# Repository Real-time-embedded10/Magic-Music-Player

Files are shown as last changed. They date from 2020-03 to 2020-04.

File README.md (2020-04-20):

Magic-Music-Player
==
This project aims to design a real-time gesture-based Magic Music System, capable of adding sound effects (including tone and/or volume) in real time using defined hand gestures.<br>

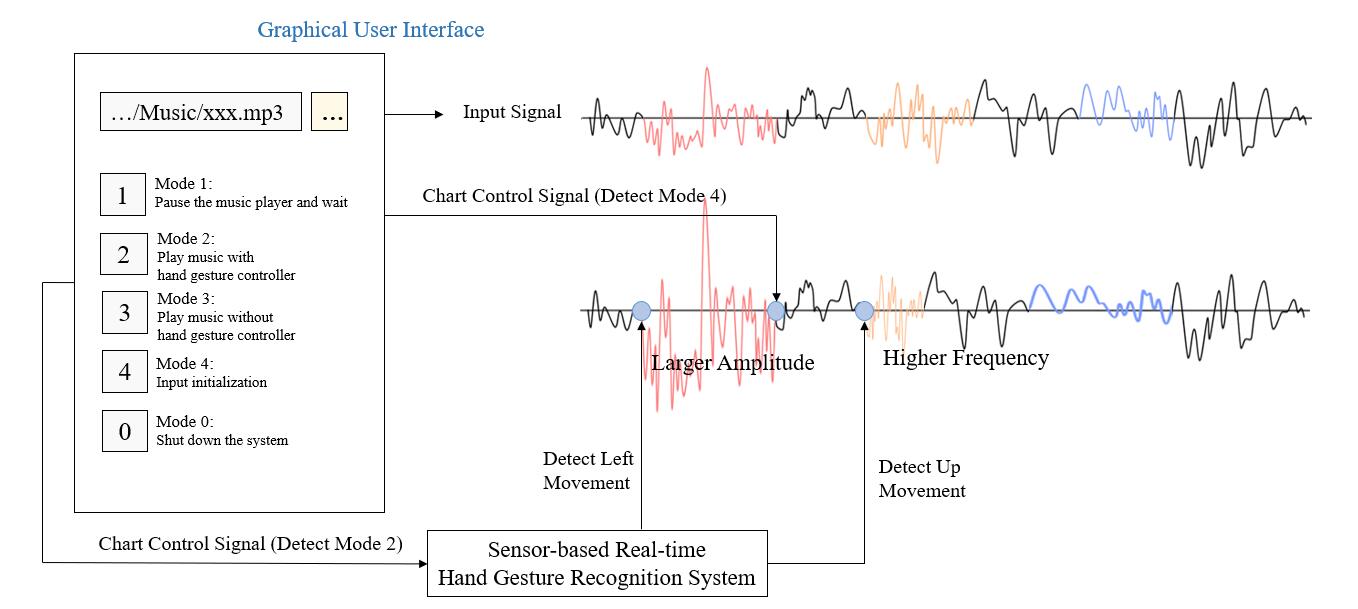
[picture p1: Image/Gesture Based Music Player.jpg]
 

Introduction
--
**Main Function**<br>
Export source from PC; <br>
Equipped control UI on PC; <br>
Recognize Hand Gesture in real time; <br>
Change music tone/volume by gestures in the process of playing music.<br>

**Hardware Requirement**<br>
Accelerometer and Gyroscope: Sensors of Hand Gesture <br>
Raspberry Pi: Real-time Hand Gesture Recognition <br>
PC: Graphical User Interface and UI Music Player <br>

**Software Requirement**<br>
I2C system to obtain data from sensors. <br>
Pre-processing method to extract useful information of hand gestures. <br>
Marchine learning model to classify hand gestures.<br>
Communication system to realize wireless connection bewteen PC and raspberry pi.<br>
Digital signal processing algorithm to process song based on control signal received from raspberry pi.<br>

Further information is available at our [wiki](https://github.com/Real-time-embedded10/Magic-Music-Player/wiki).<br>

Our Work
--
A current circuit was designed, and it can obtain information about accelerometer output, gyroscope output and temperature stably. The basic component used was MPU6050.<br>
Here is the PCB Layout and Connection. <br>
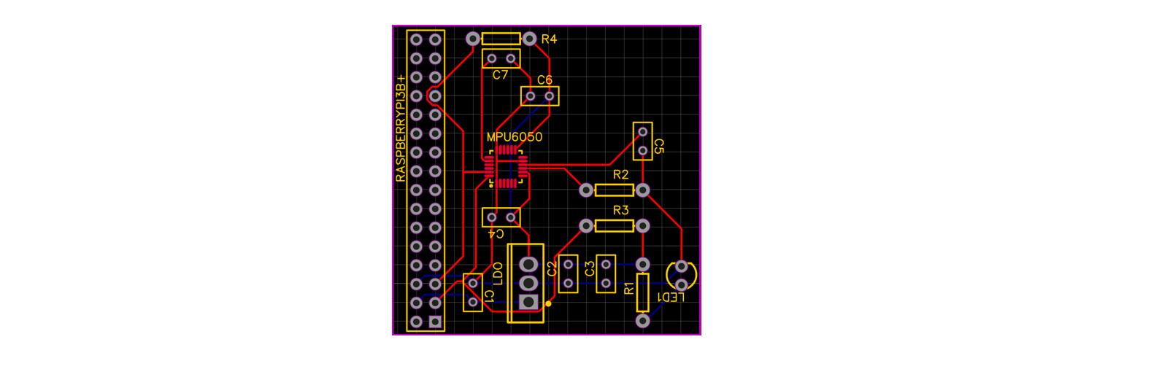
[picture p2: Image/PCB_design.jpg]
<br>

A real-time sensor-based dynamic hand gesture recognition system in raspberry pi, capable of automatically identifying whether a gesture is inputted and then translating it in the form of text, is introduced. The recognition result will be used as control signal sent to pc to control signal processing. <br>
[Here is C++ codes](https://github.com/Real-time-embedded10/Magic-Music-Player/tree/master/Software/Hand%20Gesture%20Recognition/Real%20Time%20Recognition%20System) that use Raspberry pi to recognize hand gesture in real time. <br>
Besides, a [DATABASE](https://github.com/Real-time-embedded10/Magic-Music-Player/tree/master/Software/Hand%20Gesture%20Recognition/DATABASE), including 6 hand gestures, is established. <br>
Codes used to [machine learning model training](https://github.com/Real-time-embedded10/Magic-Music-Player/tree/master/Software/Hand%20Gesture%20Recognition/Software%20Used%20in%20Database%20Establishment) and [model testing](https://github.com/Real-time-embedded10/Magic-Music-Player/tree/master/Software/Hand%20Gesture%20Recognition/Software%20Used%20in%20Testing) are also avaiable in this Repository.<br>
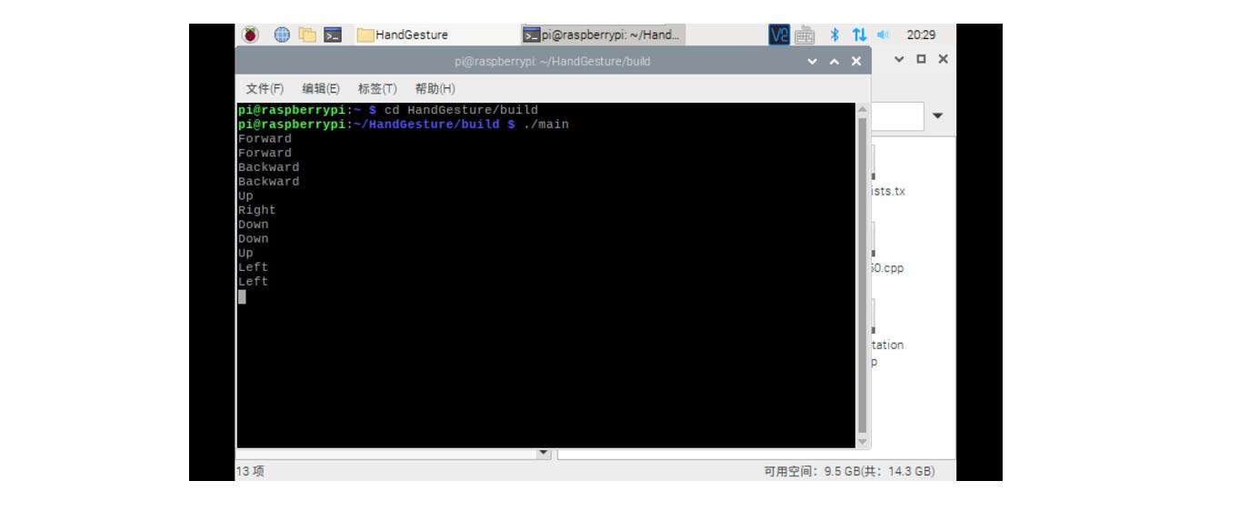
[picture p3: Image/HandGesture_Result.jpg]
<br>
<br>

This project's UI design contains two parts: [UI on the PC](https://github.com/Real-time-embedded10/Magic-Music-Player/tree/master/Software/Digital%20Signal%20Processing%20and%20UI%20Design/PC) and [UI on the raspberry Pi](https://github.com/Real-time-embedded10/Magic-Music-Player/tree/master/Software/Digital%20Signal%20Processing%20and%20UI%20Design/Raspberry%20pi).<br>
UI on the PC can work as a music player while receiving control signal generated by hand gesture to realize designed functions by calling defined libraries.<br>
UI on the raspberry pi is responsible for connecting to pc and sending signal to PC. owing to the coronavirus, UI on raspberry also helps to test the communication between PC and raspberry pi.<br>
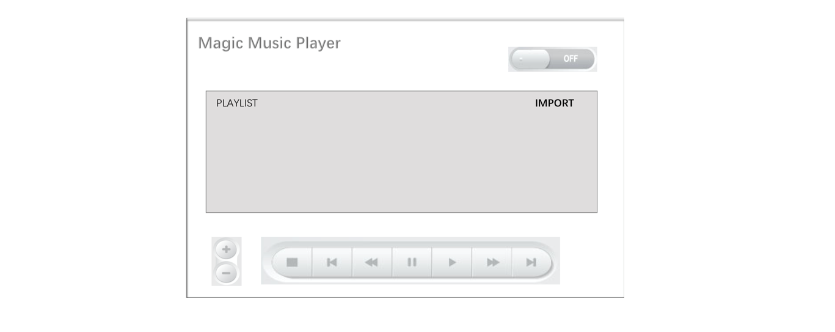
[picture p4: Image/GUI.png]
<br>

Pre-Requirement
--
Install libraries in Raspberry pi.
```
sudo apt-get install i2c-tools
sudo apt-get install wiringpi
sudo apt-get install qt5-default
sudo apt-get install qtcreator
```
and make sure that all relevant files are in one folder.<br>

To Run
--
```
cmake .
make
./main
```

Authors
--
**tashanguanyan** - Xinyun Jiang (2227272J): I2C system, Hand Gesture Recognition (Database Establishment, Machine Learning Model Training and Real-time Recoginition System).<br>
**YangDING0201** - Yang Ding (2492952D): UI MusicPlayer for PC & Rasberry Pi (Communication and Digital Signal Processing).<br>
**LianfengWu** - Lianfeng Wu (2227370W): Hardware (PCB Design). <br>
<br>
Please follow us [Twitter](https://twitter.com/MusicTeam10).<br>

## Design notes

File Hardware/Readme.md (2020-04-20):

Introduction
==
The core component in the hardware design is the MPU6050 chip, which can stably obtain the accelerometer output, gyroscope output, and temperature. The MPU6050 in the project is used to determine the direction of the hand gestures. At the same time, an LDO circuit is used in our circuit design to provide a stable 3.3V power supply for the MPU6050 to avoid burning the core chip with too high a voltage. The main component of the LDO circuit is LM7803, which can stably output 5V input voltage as 3.3V output voltage.<br>

For more information about component and circuit design, please refer to our [wiki](https://github.com/Real-time-embedded10/Magic-Music-Player/wiki/Hardware-Design).

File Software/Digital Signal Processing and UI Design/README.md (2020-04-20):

UI Design for Magic Music Player
==
The GUI design uses QT development enviroment. 

Introduction
--
**PC**<br>
This folder contains code for building GUI software on Windows and a packaged software program.[click here](https://github.com/Real-time-embedded10/Magic-Music-Player/edit/master/Software/Digital%20Signal%20Processing%20and%20UI%20Design/PC)
 <br>

* *Main Function* <br>
Import music files from PC database and build playlist; <br>
reallize basic functions of music player(Play, stop, Next track, Previous track, change playrate etc.); <br>
build communication with raspberry pi via tcp socket. <br>

**Raspberry Pi**<br>
This folder contains code for building GUI software on raspberry pi.[click here](https://github.com/Real-time-embedded10/Magic-Music-Player/tree/master/Software/Digital%20Signal%20Processing%20and%20UI%20Design/Raspberry%20pi) <br>

* *Main Function* <br>
Realize graphical connection with PC; <br>
help to test signal transmission with PC; <br>
read the signal from gesture recognition and transmit to PC. <br>
Notice: <br>
Gesture recognition files should be included in this folder to provide control signals.

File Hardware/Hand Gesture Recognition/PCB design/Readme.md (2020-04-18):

MPU6050
==
MPU-60X0 is the world's first 9-axis motion processor. It integrates a 3-axis MEMS gyroscope to measure angle, a 3-axis MEMS accelerometer to measure acceleration, and a scalable digital motion processor (DMP), which can be connected to a third-party digital sensor using I2C interface , such as a magnetometer. After expansion, it can output a 9-axis signal through its I2C interface. MPU-60X0 can also connect non-inertial digital sensors, such as pressure sensors, through its I2C interface. DMP receives and processes data from gyroscopes, accelerometers, and external sensors. The processing results can be read from DMP registers, or buffered by FIFO, and output posture-resolved data to the application side through the main I2C interface.<br>

The MPU-60X0 uses three 16-bit ADCs for the gyroscope and accelerometer, respectively, and converts the analog value it measures into a digital output. In order to accurately track fast and slow movements, the measurement range of the sensor is user-controllable, the gyro measurement range is ± 250, ± 500, ± 1000, ± 2000 ° / sec (dps), and the accelerometer measurement range is ± 2, ± 4, ± 8, ± 16g (gravity acceleration). A 1024-byte FIFO helps reduce system power consumption. Communication with all device registers uses 400kHz I2C interface or 1MHz SPI interface (SPI is only available for MPU-6000). For applications that require high-speed transmission, 20MHz SPI is available for reading and interrupting registers. In addition, a temperature sensor and an oscillator with only ± 1% variation in the working environment are embedded on the chip. The chip size is 4 × 4 × 0.9mm, and it adopts QFN package (leadless square package), which can withstand a maximum of 10000g shock, and has a programmable low-pass filter. Regarding power supply, MPU-60X0 can support VDD range 2.5V ± 5%, 3.0V ± 5%, or 3.3V ± 5%. In addition, MPU-6050 also has a VLOGIC pin, which is used to provide logic levels for I2C output. The VLOGIC voltage can be 1.8 ± 5% or VDD.<br>

**Features of MPU6050 include:**<br>
①	Digitally output 6-axis or 9-axis (requires external magnetic sensor) rotation matrix, quaternion, Euler Angle forma fusion calculation data (requires DMP support).<br>
②	3-axis angular velocity sensor (gyroscope) with 131 LSBs / ° / sec sensitivity and full-scale sensing range of ± 250, ± 500, ± 1000 and ± 2000 ° / sec.<br>
③	Integrated 3-axis acceleration sensor with programmable control range of ± 2g, ± 4g, ± 8g and ± 16g.<br>
④	Remove the sensitivity between the accelerator and the gyroscope axis, reduce the influence of the setting and the drift of the sensor.<br>
⑤	Built-in DMP engine can reduce the load of complex fusion calculation data of MCU, sensor synchronization, posture sensing, etc.<br>
⑥	Built-in operation time deviation and magnetic sensor calibration calculation technology, eliminating the need for customers to perform additional calibration.<br>
⑦	Coming with a digital temperature sensor.<br>
⑧	With digital input synchronization pin (Sync pin) supports video electronic shadow stabilization technology and GPS.<br>
⑨	Programmable interruption, support gesture recognition, panning, zooming in and out of the screen, scrolling, rapid descent interruption, high-G interruption, zero motion sensing, touch sensing, shaking sensing function.<br>
⑩	VDD power supply voltage is 2.5V ± 5%, 3.0V ± 5%, 3.3V ± 5%; VLOGIC can be as low as 1.8V ± 5%.<br>
⑪	Gyroscope working current: 5mA, gyroscope standby current: 5uA; accelerator working current: 500uA, accelerator power saving mode current: 40uA @ 10Hz.<br>
⑫	Comes with 1024-byte FIFO, which helps reduce system power consumption.<br>
⑬	I2C communication interface up to 400Khz.<br>
⑭	Ultra-small package size: 4x4x0.9mm (QFN).<br>

**Circuit Design**<br>
The Block Diagram of MPU6050:<br>
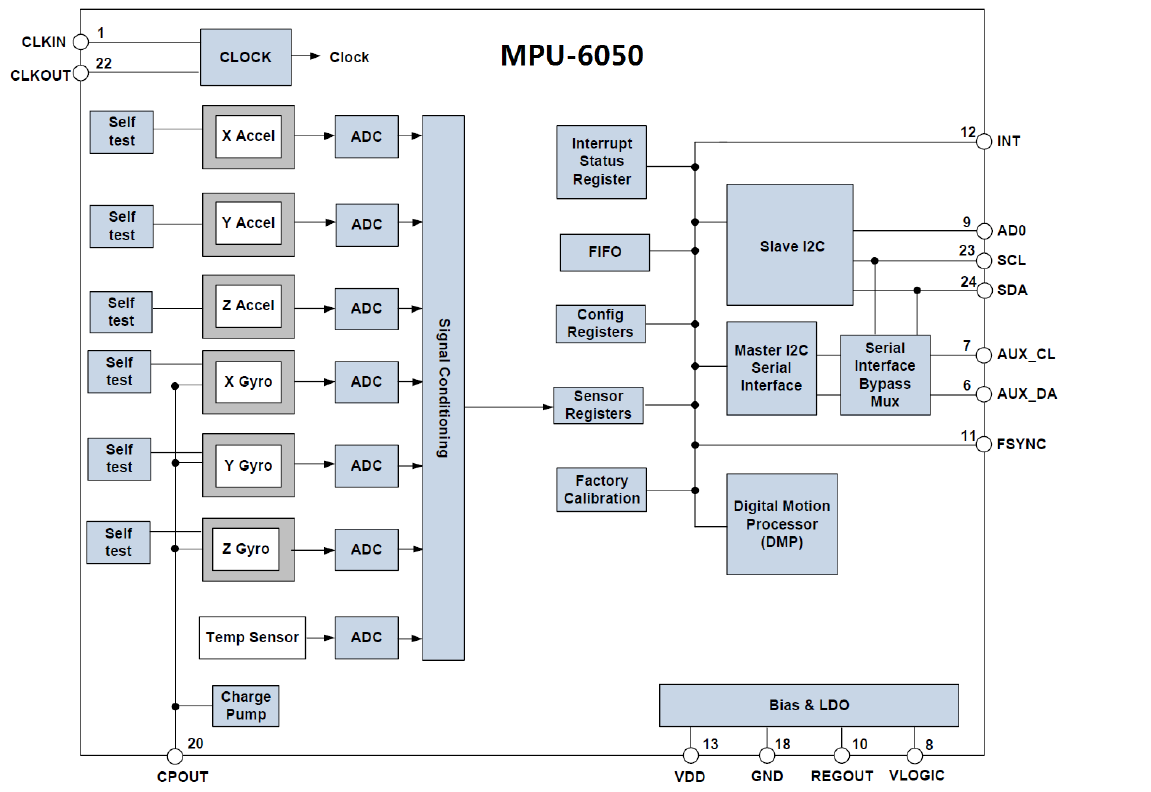
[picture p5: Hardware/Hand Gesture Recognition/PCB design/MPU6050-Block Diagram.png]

The above picture is the internal structure diagram of MPU6050. Among them, SCL and SDA are I2C interfaces connected to MCU. Raspberry Pi controls MPU6050 through this I2C interface. There is also an I2C interface: AUX_CL and AUX_DA. This interface can be used to connect external slave devices. For example, magnetic sensors, so that a nine-axis sensor can be formed. VLOGIC is the voltage of the IO port. This pin can be as low as 1.8V. We generally connect it directly to VDD. AD0 is the address control pin from the I2C interface (connected to MCU). This pin controls the lowest bit of the IIC address. If it is connected to GND, the I2C address of MPU6050 is: 0X68, if it is connected to VDD, it is 0X69. Note: The address here does not contain the lowest bit of data transmission (the lowest bit is used to indicate read and write).<br>

The Schematic Circuit Diagram:<br>
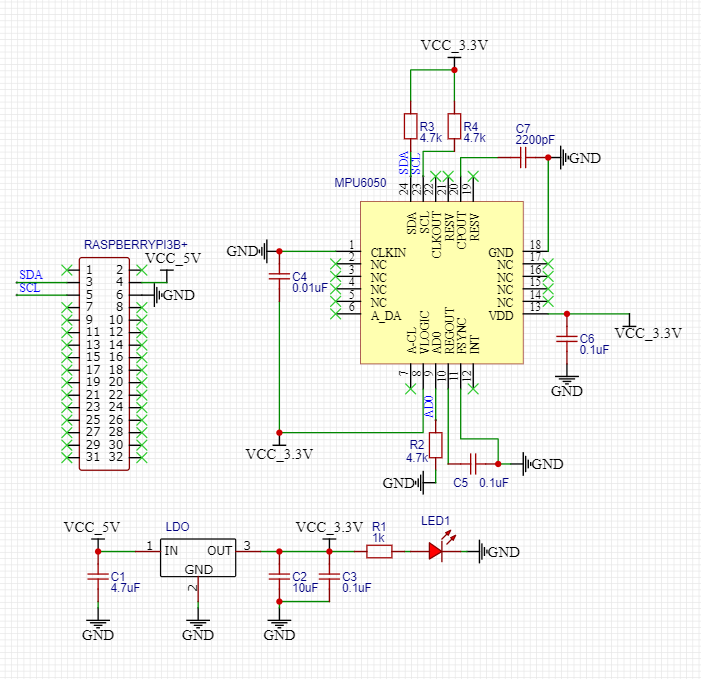
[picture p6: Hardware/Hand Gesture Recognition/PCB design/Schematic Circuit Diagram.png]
<br>
Because the voltage working range of MPU60X0 is 2.375V-3.46V, a 3.3V low dropout voltage regulator circuit is added to the circuit diagram design to power the MPU6050, so the MPU6050 chip can be connected to the 3.3V or 5V output power of the Raspberry Pi. Pull-up resistors of 4.7K are added at both SDA and SCL, and external pull-up resistors can be eliminated. In addition, there is also a 4.7K pull-down resistor at AD0. In the actual connection, AD0 is floating, and the default I2C address is 0X68.<br>

For detailed information or data related to MPU6050, please refer to [the uploaded datasheet](https://github.com/Real-time-embedded10/Magic-Music-Player/blob/master/Hardware/Hand%20Gesture%20Recognition/Datasheet/MPU-6000-Datasheet.pdf).<br>

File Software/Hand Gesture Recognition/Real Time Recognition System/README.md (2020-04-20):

Real Time Recognition System
==
Here are four demos (unit tests) provided to show how to acheive each stage of the proposed system to recognize gesture on Raspberry pi in real time. <br>
To obtain detail explanation about, for example, why we do this process or how to determine parameters, please see our [wiki](https://github.com/Real-time-embedded10/Magic-Music-Player/wiki/Proposed-System).<br>

Requirement
--
[WiringPi library](http://wiringpi.com/)<br>
```
sudo apt-get install wiringpi
```
MPU6050_demo
--
This demo is used to show how to achieve data collection in real time at 20Hz sampling rate. <br>
```
while (sample_time - last_sample_time < 50) {
            sample_time = millis();
}
last_sample_time = sample_time;
```
Sampling rate can change, but it’s better not to do this, or almost all the parameters of the subsequent processing (such as segmentation) need to be modified, and a new machine learning model should be re-trained. 20Hz is a great sampling rate, according to the results of our many tests.<br>
<br>
Make sure that files: `CMakeLists.txt`, `MPU6050_Registers.h`, `MPU6050_Types.h`, `MPU6050.h`, `MPU6050.cpp` and `MPU6050_demo.cpp` are in one folder. <br>

Segmentation_demo
--
This demo is used to show how to achieve hand segmentation in real time, and record 30 useful data of each axis for each gesture. <br>
```
seg.SegmentationProcess(xa, ya, za, xg, yg, zg);
if (seg.GestureDetectResult == 1) {
    std::cout << "YES" << std::endl;
}
```
Make sure that files: `CMakeLists.txt`, `MPU6050_Registers.h`, `MPU6050_Types.h`, `MPU6050.h`, `MPU6050.cpp`, `Segmentation.h`,`Segmentation.cpp` and `Segmentation_demo.cpp` are in one folder. <br>

FeatureExtraction_demo
--
This demo is used to show how to achieve feature extraction in real time, and extract 21 key features for each gesture. <br>
```
fea.extractionProcess(seg.recordTargetXA, seg.recordTargetYA, seg.recordTargetZA, seg.recordTargetXG, seg.recordTargetYG, seg.recordTargetZG);
```
Make sure that files: `CMakeLists.txt`, `MPU6050_Registers.h`, `MPU6050_Types.h`, `MPU6050.h`, `MPU6050.cpp`, `Segmentation.h`,`Segmentation.cpp`, `FeatureExtraction.h`, `FeatureExtraction.cpp` and `FeatureExtraction_demo.cpp` are in one folder. <br>

Classification_demo
--
This demo is used to show how to recognize gesture in real time, and the correspondence between classification results and gestures is as follows. <br>
```
cla.classify(fea.extractedFeature);
std::cout << cla.classificationResult << std::endl;
```
|ClassificationResult| Gesture |
|---|---|
| 1 | Forward |
| 2 | Backward  |
| 3 | Left |
| 4 | Right |
| 5 | Up |
| 6 | Down |
<br>

Make sure that files: `CMakeLists.txt`, `MPU6050_Registers.h`, `MPU6050_Types.h`, `MPU6050.h`, `MPU6050.cpp`, `Segmentation.h`,`Segmentation.cpp`, `FeatureExtraction.h`, `FeatureExtraction.cpp`, `Classification.h`, `Classification.cpp` and `Classification_demo.cpp` are in one folder. <br>

Run the demo
--
```
cmake .
make
./main
```
Tests
--
Two cross validation methods are proposed to test classification successful rate. Please [click here](https://github.com/Real-time-embedded10/Magic-Music-Player/tree/master/Software/Hand%20Gesture%20Recognition/Software%20Used%20in%20Testing)

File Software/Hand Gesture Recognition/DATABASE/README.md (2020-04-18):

DATABASE
--
A database containing six gestures (forward, backward, right, left, up and down) was built, including a total of 1,080 samples played by six signers (30 samples pre gesture pre person). <br>
Codes to obtain Original Data: please [click here](https://github.com/Real-time-embedded10/Magic-Music-Player/tree/master/Software/Hand%20Gesture%20Recognition/Software%20Used%20in%20Database%20Establishment/1.%20Dat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).<br>
Codes to pre-process original database and obtain Pre-processed Data: please [click here](https://github.com/Real-time-embedded10/Magic-Music-Player/tree/master/Software/Hand%20Gesture%20Recognition/Software%20Used%20in%20Database%20Establishment/2.%20Pre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).<br>

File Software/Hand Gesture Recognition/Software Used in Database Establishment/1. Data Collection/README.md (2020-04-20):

Data Collection
==
Detailed instruction and explanation is at our [wiki](https://github.com/Real-time-embedded10/Magic-Music-Player/wiki/Data-Collection).<br>
<br>
Since it is more convenient to collect data by python than C++ (every time changing the stored file name, you don't need to re-run `make` and then `./main`), this file was written by python.<br>
[Here](https://github.com/Real-time-embedded10/Magic-Music-Player/tree/master/Software/Hand%20Gesture%20Recognition/DATABASE/Original%20Data) is the original DATABASE collected. <br>

Requirement
--
Install I2C library.<br>
```
sudo apt-get install i2c-tools
```

Detect whether I2C device is successfully connected and find the corresponding address.
```
sudo i2cdetect -y 1
```

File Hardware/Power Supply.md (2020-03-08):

The recommended power supply for the Raspberry Pi 3B is 5V2.5A ~ 5V3A. It is generally considered that 5V ± 5% (that is, 4.75V ~ 5.25V) is an acceptable voltage range, but exceeding (or almost beyond) this range is prone to problems. Although the power adapters all output 5V nominally, as the current consumption increases, the voltage will gradually decrease. If the voltage drops to a certain level, the Raspberry Pi will be underpowered and cannot work properly.

When the power supply voltage or current does not reach 5V / 2A, the main symptoms of insufficient power supply of the Raspberry Pi are:

  -There are corresponding symbols in the upper right corner of the monitor linked to the HDMI interface or the upper right corner of the system desktop.
  
  -The main board's red indicator is blinking or off.
  
  -The display flickers frequently.
  
  -The system starts repeatedly.
  
When the above situations occur, although the Raspberry Pi will work, it will be unstable and even crash.

Several possible ways to power the Raspberry Pi:
  
  Method 1:
Power is supplied through the Micro USB interface, and 5V / 2A DC power is sufficient. This method is usually used when experimenting early in the design. Depending on the requirements of the final product, other mobile power may need to be provided for the Raspberry Pi.
  
  Method 2: 
Power is supplied through the GPIO interface. The Raspberry Pi's GPIO interface can also accept DC input, but it is different from the first method: the GPIO power supply has no fuse. When the voltage or current is too high, it is easy to burn the board directly. The wiring method is as follows: Connect the positive pole of 5v current to pin 2 and the negative pole to pin 6.
  
  Method 3: 
Direct power supply via USB interface. Directly use the USB interface to reverse power the Raspberry Pi. However, this method requires some changes to the Raspberry Pi's motherboard to supply power normally. Therefore, this method is generally not recommended.

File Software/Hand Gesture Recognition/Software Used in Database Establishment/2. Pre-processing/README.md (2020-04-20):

Pre-processing
--
File `Data_Analysis.m` is used as a tool to determine segmentation parameters, and segmentation process is achieved in file `Segmentation.py`. For the complete pre-processed database, please [clike here](https://github.com/Real-time-embedded10/Magic-Music-Player/tree/master/Software/Hand%20Gesture%20Recognition/DATABASE/Pre_processed%20Data).<br>
Detailed instruction and explanation is at our [wiki](https://github.com/Real-time-embedded10/Magic-Music-Player/wiki/Pre-processing).
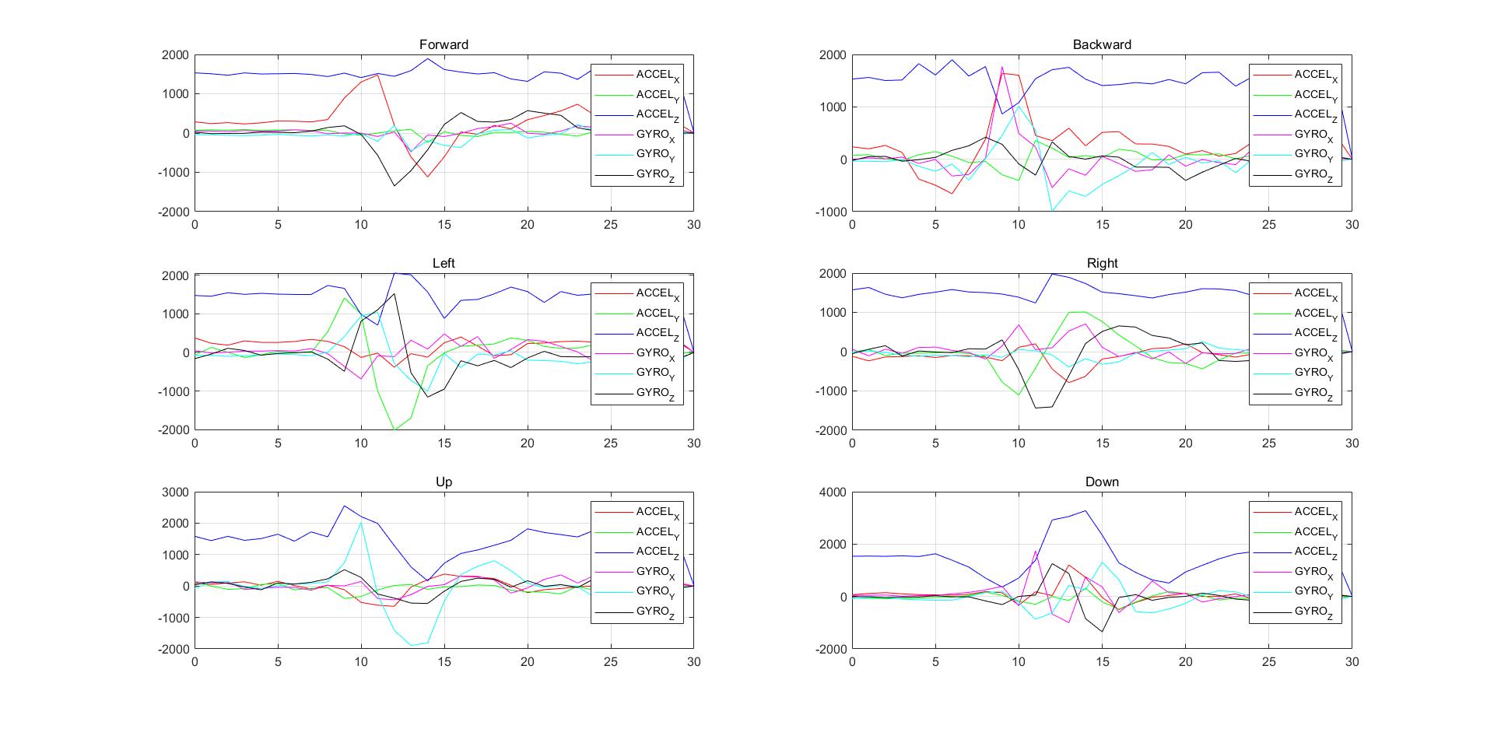
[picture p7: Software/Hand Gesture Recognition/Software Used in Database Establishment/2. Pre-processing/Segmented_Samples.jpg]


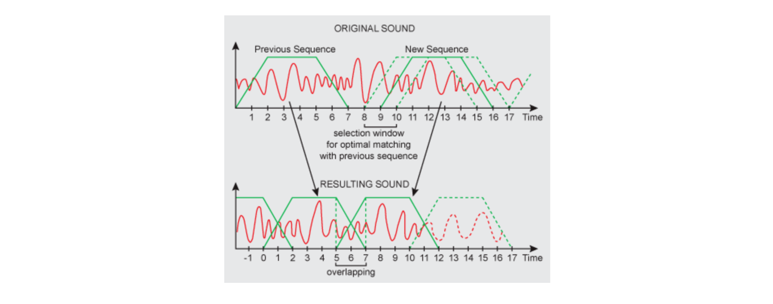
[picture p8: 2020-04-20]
Image/Theory of the time domain approach.png

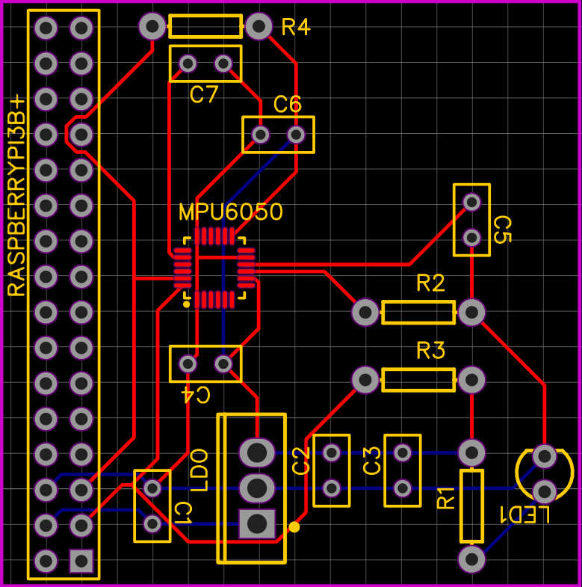
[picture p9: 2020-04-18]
Hardware/PCB_Design.png

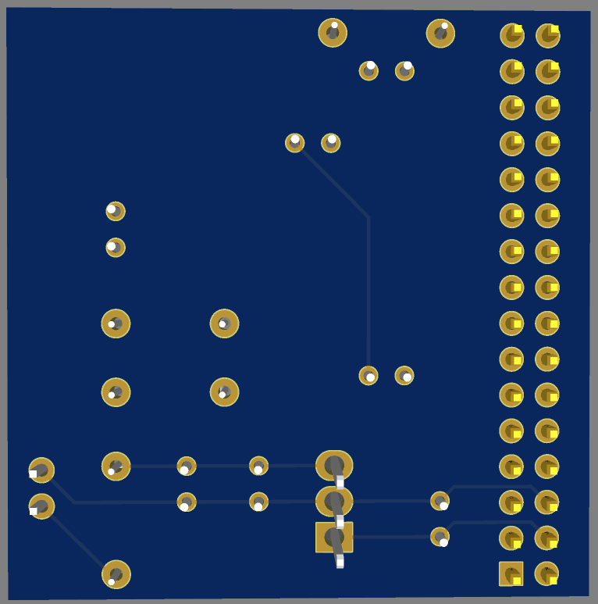
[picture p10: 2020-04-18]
Hardware/physical_preview_back.png

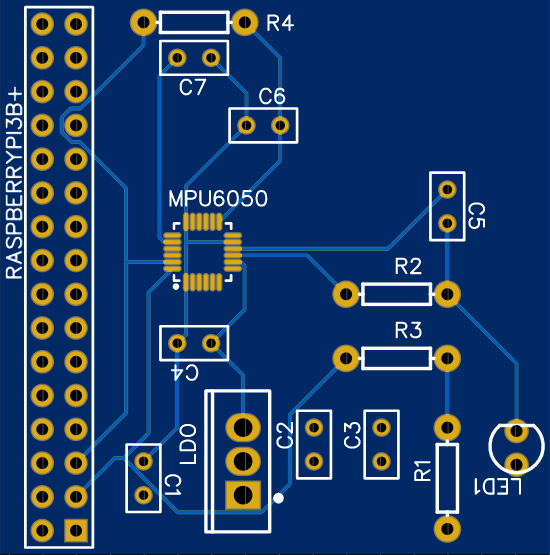
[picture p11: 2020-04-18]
Hardware/physical_preview.png

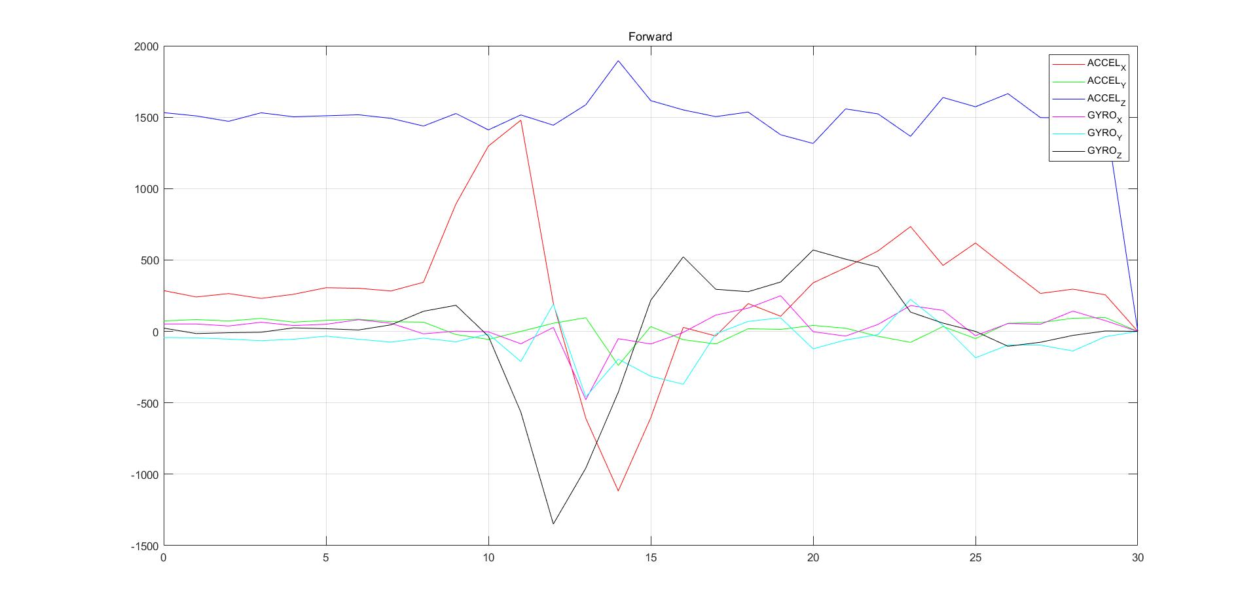
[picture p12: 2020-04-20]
Software/Hand Gesture Recognition/Software Used in Database Establishment/2. Pre-processing/Figure/Forward.jpg

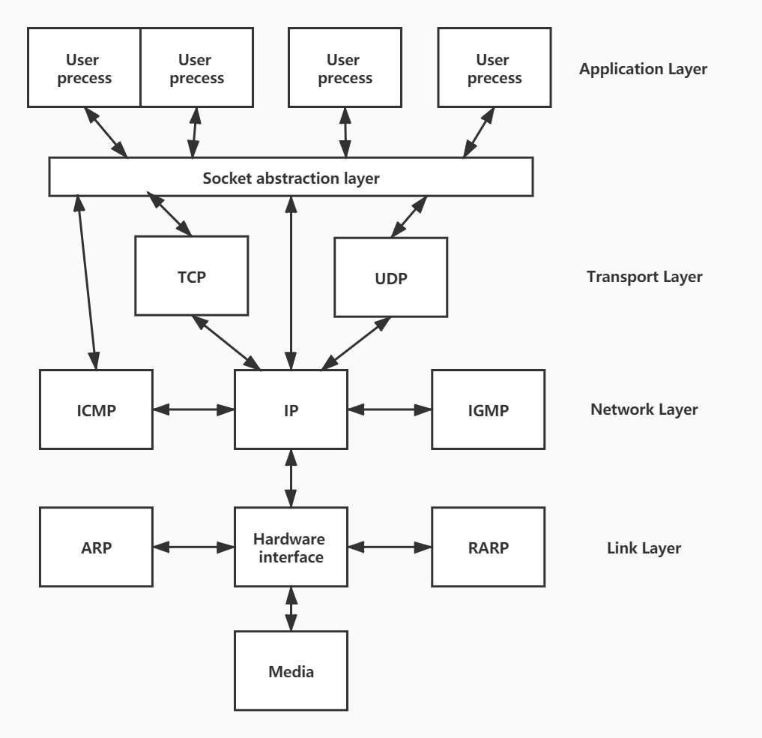
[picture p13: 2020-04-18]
Image/TCP relationship structure.png

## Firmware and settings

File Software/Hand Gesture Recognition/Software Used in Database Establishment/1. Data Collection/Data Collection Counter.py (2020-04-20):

import smbus
import time
import numpy as np

# Define register addresses
MPU_ACCEL_XOUT1 = 0x3b
MPU_ACCEL_XOUT2 = 0x3c
MPU_ACCEL_YOUT1 = 0x3d
MPU_ACCEL_YOUT2 = 0x3e
MPU_ACCEL_ZOUT1 = 0x3f
MPU_ACCEL_ZOUT2 = 0x40
MPU_GYRO_XOUT1 = 0x43
MPU_GYRO_XOUT2 = 0x44
MPU_GYRO_YOUT1 = 0x45
MPU_GYRO_YOUT2 = 0x46
MPU_GYRO_ZOUT1 = 0x47
MPU_GYRO_ZOUT2 = 0x48
MPU_POWER1 = 0x6b
MPU_POWER2 = 0x6c

# Default i2c address of MPU6050, and it can also be obtained by "sudo i2cdetect -y 1"
address = 0x68

# Read information from sensor
def read_word_2c(adr):
    val = (bus.read_byte_data(address, adr) << 8) + bus.read_byte_data(address, adr + 1)
    # The acceleration range is set from -8g to 8g.
    if (val >= 0x8000):
        return -((65535 - val) + 1)
    else:
        return val

bus = smbus.SMBus(1) # 1 means '/dev/i2c-1'
bus.write_byte_data(address, MPU_POWER1, 0)

# Initialize the matrix that will be used for the counter
test_old = np.zeros((23, 1), dtype='int16')
test_new = np.zeros((23, 1), dtype='int16')
number = 0

while (1):
    # Read information from sensor
    AX = read_word_2c(MPU_ACCEL_XOUT1)
    AY = read_word_2c(MPU_ACCEL_YOUT1)
    AZ = read_word_2c(MPU_ACCEL_ZOUT1)
    GX = read_word_2c(MPU_GYRO_XOUT1)
    GY = read_word_2c(MPU_GYRO_YOUT1)
    GZ = read_word_2c(MPU_GYRO_ZOUT1)
    
    # Pre-process information read from sensor for better detection result.
    AX = AX * 150
    AY = AY * 300
    AZ = AZ * 100
    GX = GX * 10
    GY = GY * 10
    GZ = GZ * 10
    
    # Detect large change of data
    test = 0
    if ((AX > 700) or (AX < -700)):
        test = 1
    else:
        if ((AY > 700) or (AY < -700)):
            test = 1
        else:
            if ((AZ > 2200) or (AZ < 700)):
                test = 1
            else:
                if ((GX > 700) or (GX < -700)):
                    test = 1
                else:
                    if ((GY > 700) or (GY < -700)):
                        test = 1
                    else:
                        if ((GZ > 700) or (GZ < -700)):
                            test = 1
                        else:
                            test = 0
    
    test_new[22] = test
    for r in range(22):
        test_new[r] = test_old[r+1]  # the r itme of position_judge is equal to the (r-1) itme of postion.
    test_old = test_new
   
    # Counter
    if (sum(test_new[0:20]) == 0) & (test_new[20] == 1) & (sum(test_new[21:23]) != 0):
        number = number+1
        print(number)
          

    AX2 = str(AX)
    AY2 = str(AY)
    AZ2 = str(AZ)
    GX2 = str(GX)
    GY2 = str(GY)
    GZ2 = str(GZ)
    
    # Save information in './result.txt'
    with open('./result.txt', 'a') as file_handle:
        file_handle.write(AX2)
        file_handle.write('  ')
        file_handle.write(AY2)
        file_handle.write('  ')
        file_handle.write(AZ2)
        file_handle.write('  ')
        file_handle.write(GX2)
        file_handle.write('  ')
        file_handle.write(GY2)
        file_handle.write('  ')
        file_handle.write(GZ2)
        file_handle.write('\n')
    time.sleep(0.05)

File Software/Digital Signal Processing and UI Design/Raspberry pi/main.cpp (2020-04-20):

#pragma execution_character_set("utf-8")
#include "mainwidget.h"
#include <QApplication>
#include <QDesktopWidget>
#include <QMessageBox>
#include <QTextCodec>
#include <QProcess>
#include <QFontDatabase>
#include <QDateTime>
#include <QDebug>
#include <QFile>
#include <QDir>
#include <QIcon>

int main(int argc, char *argv[])
{

    QApplication a(argc, argv);
    //    initDebug();
    //    qInstallMessageHandler(outputMessage);
#if (QT_VERSION <= QT_VERSION_CHECK(5,0,0))
#if _MSC_VER
    QTextCodec *codec = QTextCodec::codecForName("gbk");
#else
    QTextCodec *codec = QTextCodec::codecForName("utf-8");
#endif
    QTextCodec::setCodecForLocale(codec);
    QTextCodec::setCodecForCStrings(codec);
    QTextCodec::setCodecForTr(codec);
#else
    QTextCodec *codec = QTextCodec::codecForName("utf-8");
    QTextCodec::setCodecForLocale(codec);
#endif
    a.setWindowIcon(QIcon(":/main.ico"));

    QString qssFile = ":/qss/darkblue.css";
    QFile file(qssFile);

    if (file.open(QFile::ReadOnly)) {
        QString qss = QLatin1String(file.readAll());
        QString paletteColor = qss.mid(20, 7);
        qApp->setPalette(QPalette(QColor(paletteColor)));
        qApp->setStyleSheet(qss);
        file.close();
    }
    QString starttime = "2020-03-16 12:00:01";
    QString endtime = QDateTime::currentDateTime().toString("yyyy-MM-dd hh:mm:ss");
    QDateTime start = QDateTime::fromString(starttime, "yyyy-MM-dd hh:mm:ss");
    QDateTime end = QDateTime::fromString(endtime, "yyyy-MM-dd hh:mm:ss");
    uint stime = start.toTime_t();
    uint etime = end.toTime_t();
    int ndaysec = 24*60*60;
    MainWidget w;
    w.setWindowTitle("MPU");
    int day = (etime - stime)/(ndaysec) + ((etime - stime)%(ndaysec)+(ndaysec-1))/(ndaysec) - 1;
    qDebug() << "Day ---------------------------------------------------- " << day;
//    if(day > 500){
//        QMessageBox::critical(nullptr, "Error", QString("Fail to start the project, please contact the developer!"));
//    }else{
        w.show();
//    }
    return a.exec();
}

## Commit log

2020-02-27 Rename Software/Hand Gesture Recognition/2.1Sample_Analysis.py to Software/Hand Gesture Recognition/2.Pre-Process/2.1.Sample_Analysis.py
2020-03-07 Create Power Supply
2020-03-07 Create Power
2020-03-07 Update Power
2020-04-18 Rename Software/Wireless Communication/Socket Communication/socket_client.cpp to Software/Wireless Communication/socket_client.cpp
2020-04-18 Rename Software/Wireless Communication/Socket Communication/socket_server.cpp to Software/Wireless Communication/socket_server.cpp
2020-04-18 Rename Hardware/Power Supply/README.md to Hardware/Power Supply.txt
2020-04-18 Rename Power Supply.txt to Power Supply.md
2020-04-18 Update and rename Hardware/Hand Gesture Recognition/PCB design/Readme.md to Hardware/Readme.md
2020-04-19 Create Raspberry Pi
